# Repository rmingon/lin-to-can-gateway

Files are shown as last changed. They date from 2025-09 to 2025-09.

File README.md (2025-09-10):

# Secure LIN-to-CAN Gateway with AES Encryption

This project implements a **custom PCB gateway** that bridges **Local Interconnect Network (LIN)** and **Controller Area Network (CAN)** communication buses. It integrates **AES-based cryptographic software** to ensure secure message transfer across networks, making it suitable for both embedded research and industrial-grade applications.

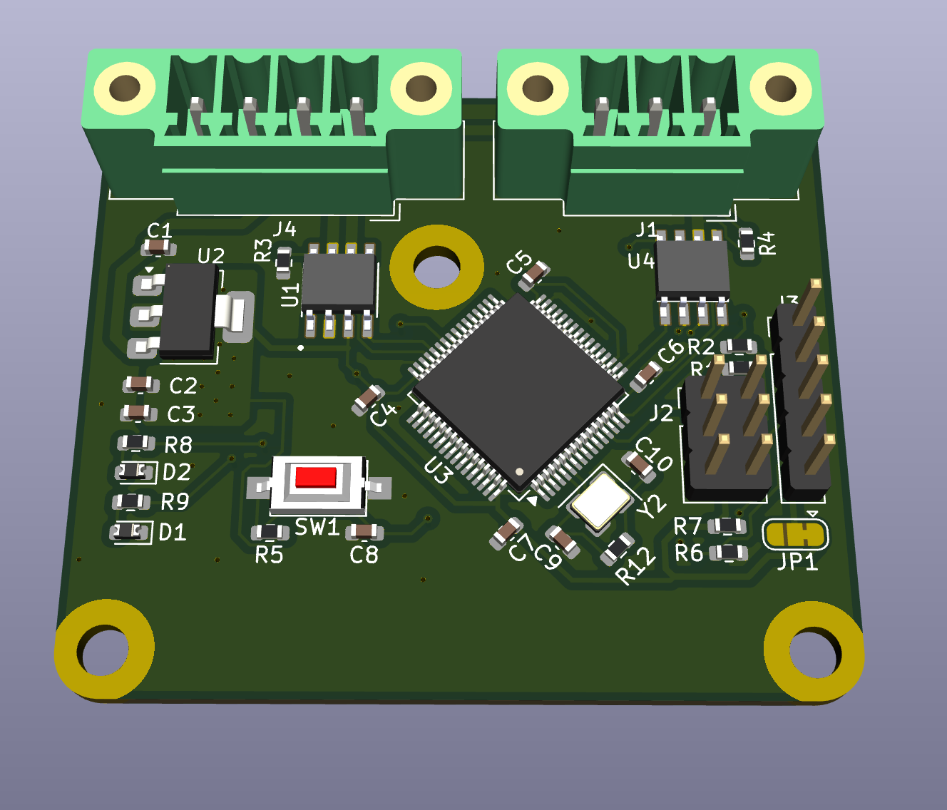
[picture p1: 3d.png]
3D


---

## Features

- **MCU Core:** STM32F107 microcontroller
- **CAN Transceiver:** MCP2551 for reliable CAN bus communication
- **LIN Transceiver:** TJA1020 for LIN bus interface
- **Crypto Layer:** AES software encryption for secure message payloads
- **Voltage Regulation:** On-board LM317 regulator provides stable 3.3V supply
- **Programming & Debugging:** SWD interface for firmware upload and debugging
- **User Interface:** Reset button, status LEDs, and configuration jumper
- **Compact PCB Design:** 2-layer PCB optimized for automotive and embedded systems

---

## Hardware Overview

### Major Components

- **U3 – STM32F107**: 32-bit ARM Cortex-M3 MCU
- **U1 – MCP2551**: High-speed CAN transceiver
- **U4 – TJA1020**: LIN transceiver for automotive communication
- **U2 – LM317**: Adjustable linear regulator, set to 3.3V output
- **Y2**: External crystal oscillator for precise MCU timing

### Connectors

- **J1 / J2**: LIN and CAN bus connections
- **J3**: SWD programming/debugging interface
- **JP1**: Boot configuration jumper

---

## Firmware

The firmware implements:

- LIN message reception, decryption, and forwarding to CAN
- CAN message reception, encryption, and forwarding to LIN
- AES-based payload encryption for secure communication
- Error handling and bus monitoring

---

## Applications

- **Automotive Systems:** Securely bridging LIN and CAN buses in vehicles
- **Industrial Automation:** Protecting data integrity across mixed communication buses
- **IoT Gateways:** Encrypted transport between legacy fieldbuses and modern networks
- **Research & Development:** Testing secure communication protocols in embedded systems

---

## Getting Started

1. **Assemble the PCB** with the provided KiCad files and BOM.
2. **Flash the firmware** via the SWD interface.
3. **Connect LIN and CAN networks** to the respective terminals.
4. **Test secure message transfer** with your chosen CAN/LIN monitoring tools.

---

## License

This project is licensed under the CERN Open Hardware Licence Version 2 - Strongly Reciprocal (CERN-OHL-S v2).

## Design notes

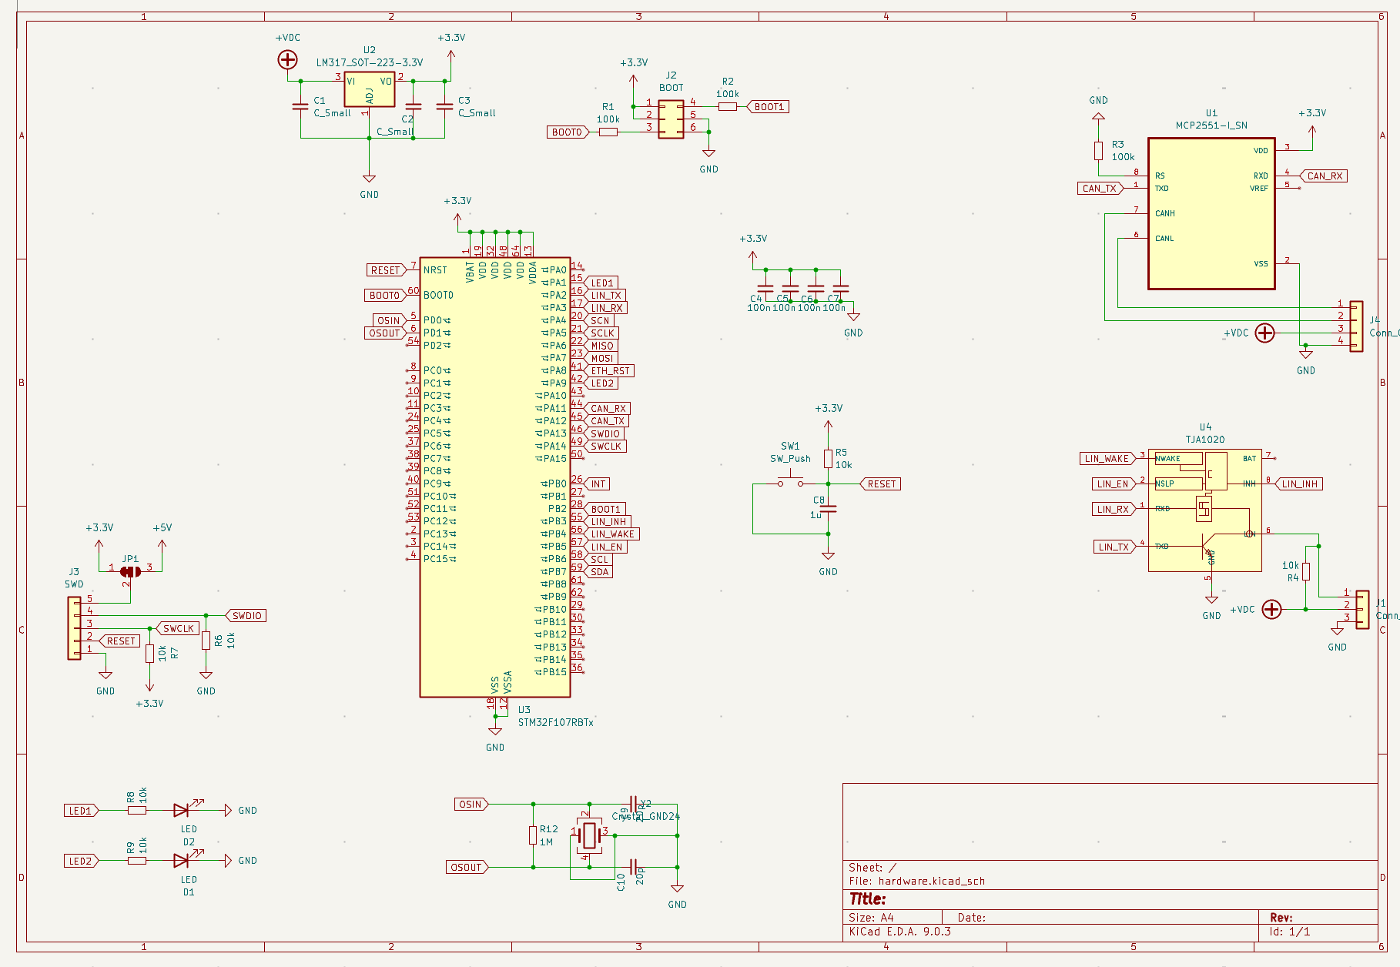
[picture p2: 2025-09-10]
schematic.png

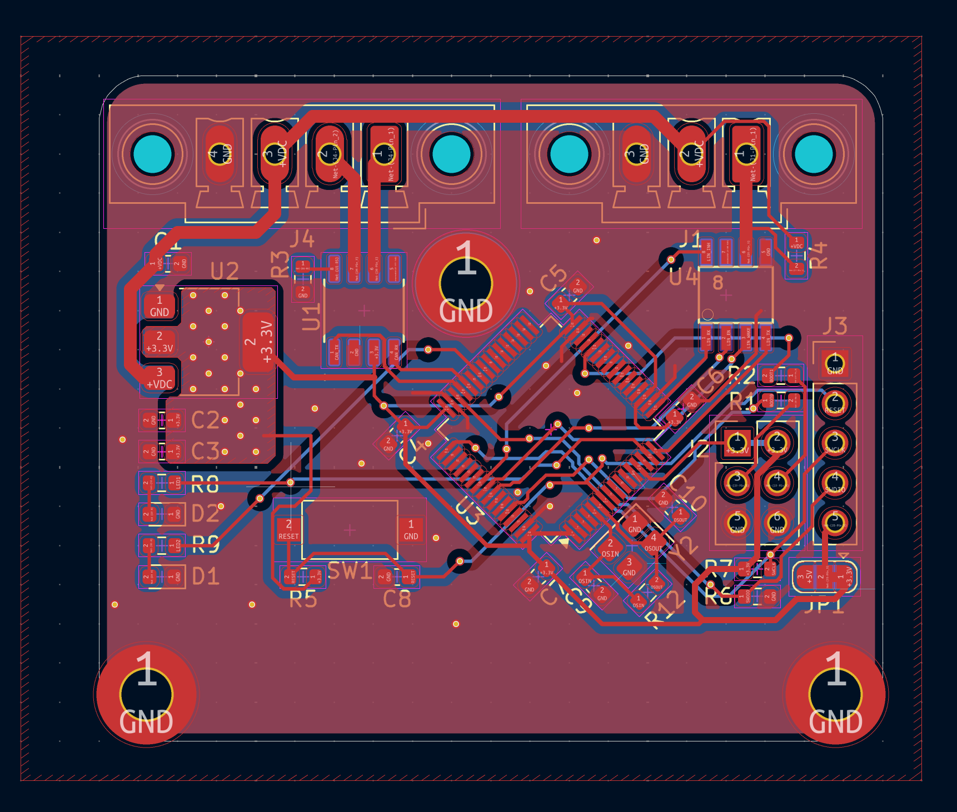
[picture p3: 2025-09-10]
pcb.png

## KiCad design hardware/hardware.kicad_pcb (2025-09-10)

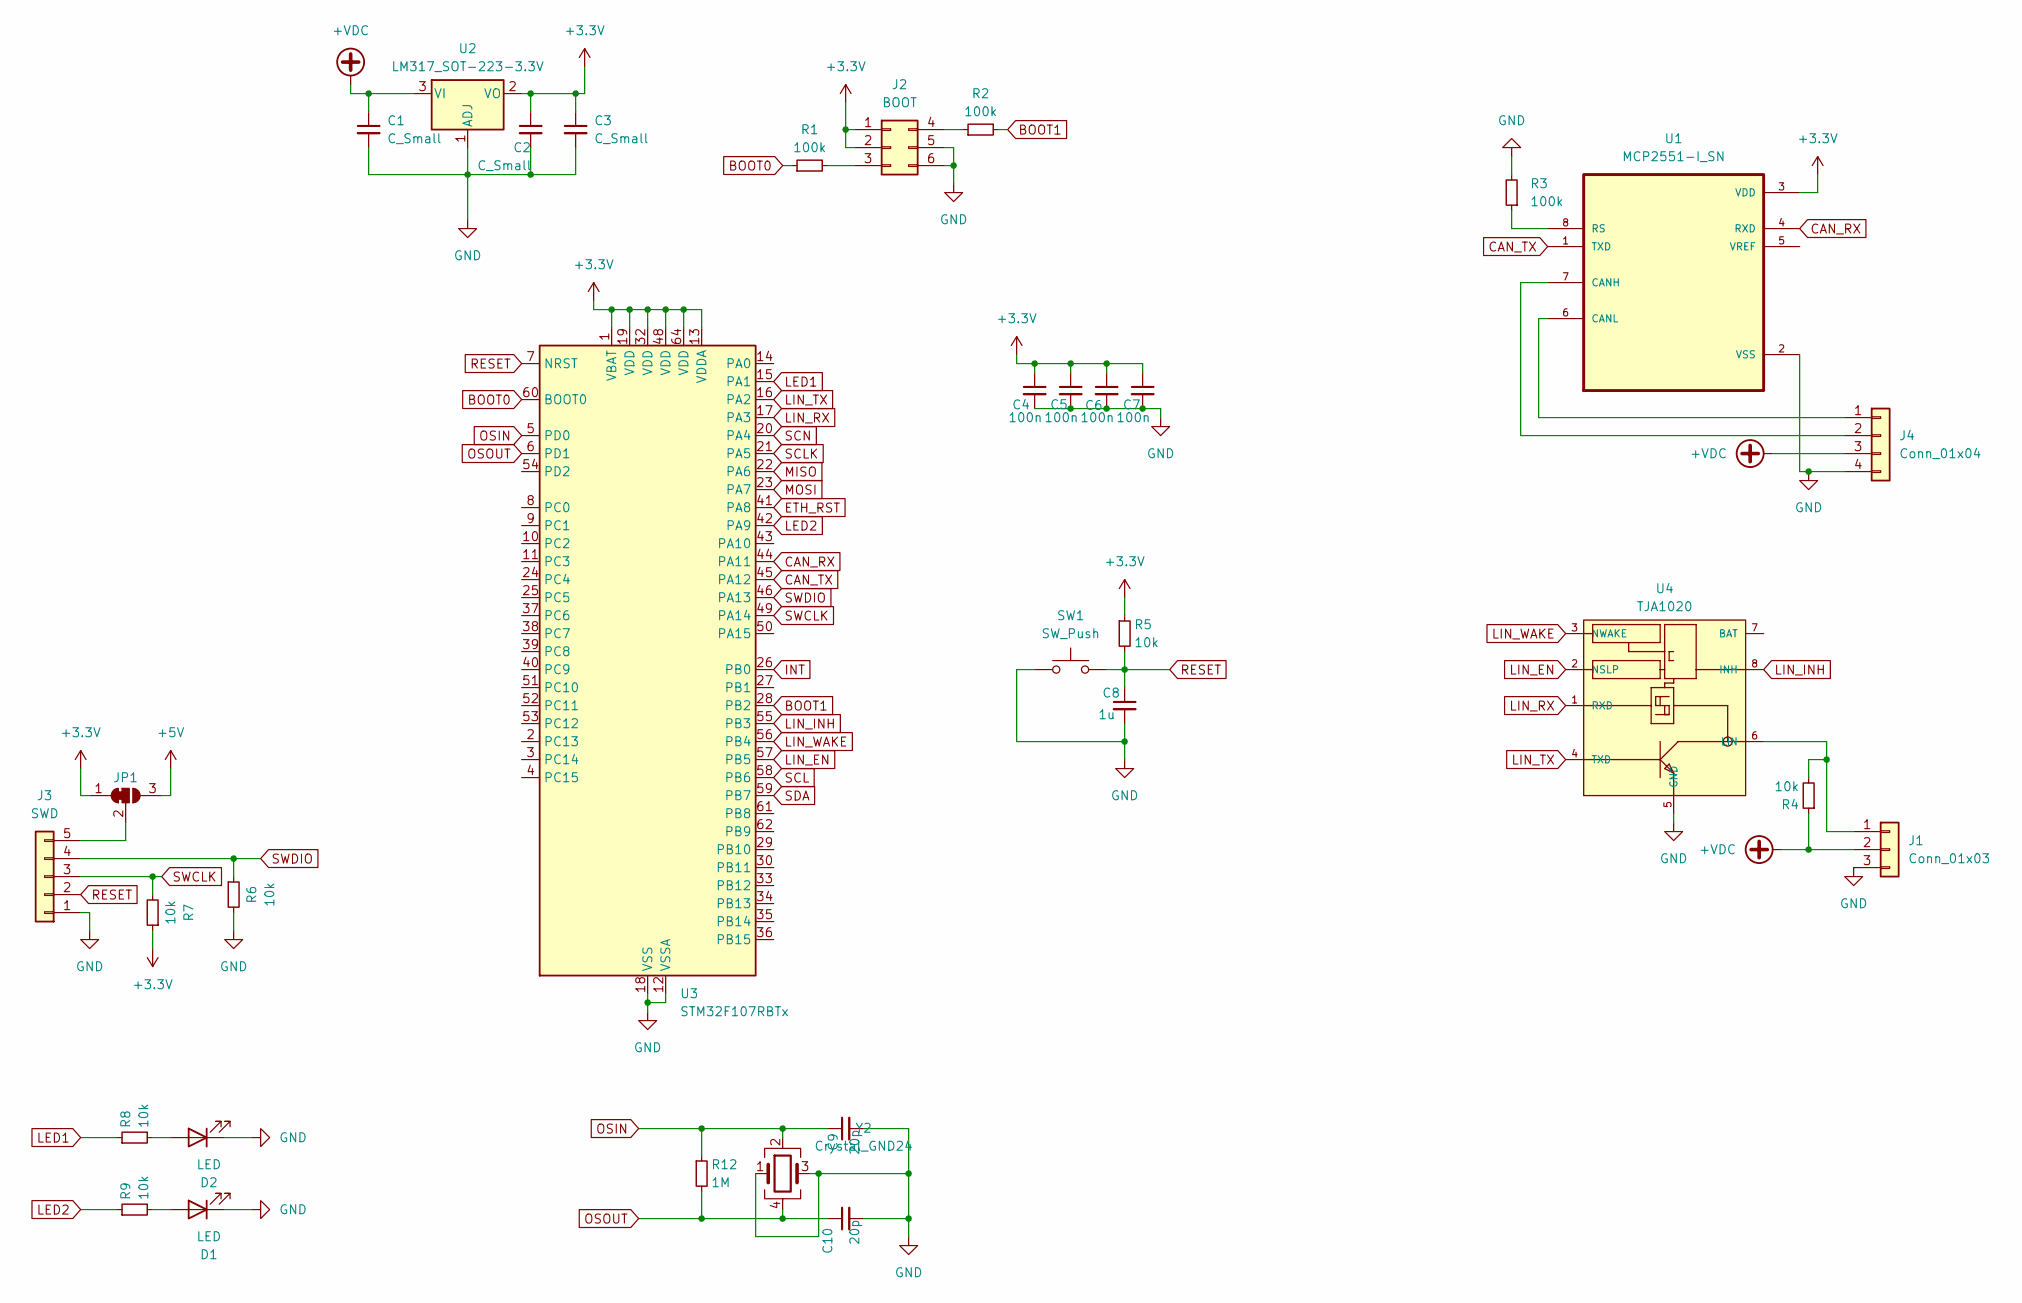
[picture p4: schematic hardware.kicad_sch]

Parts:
C1, C2, C3: C_Small; C_0603_1608Metric
C4, C5, C6, C7: 100n; C_0603_1608Metric
C8: 1u; C_0603_1608Metric
C9, C10: 20p; C_0603_1608Metric
D1, D2: LED; D_0603_1608Metric
J1: Conn_01x03; PhoenixContact_MCV_1,5_3-GF-3.5_1x03_P3.50mm_Vertical_Threa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
J2: BOOT; PinHeader_2x03_P2.54mm_Vertical_SMD
J3: SWD; PinHeader_1x05_P2.54mm_Vertical
J4: Conn_01x04; PhoenixContact_MCV_1,5_4-GF-3.5_1x04_P3.50mm_Vertical_Threa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
JP1: SolderJumper_3_Bridged12; SolderJumper-3_P1.3mm_Bridged12_RoundedPad1.0x1.5mm
R1, R2, R3: 100k; R_0603_1608Metric
R4, R5, R6, R7, R8, R9: 10k; R_0603_1608Metric
R12: 1M; R_0603_1608Metric
SW1: SW_Push; SW_SPST_CK_RS282G05A3
U1: MCP2551-I_SN; SOIC127P599X175-8N
U2: LM317_SOT-223-3.3V; SOT-223-3_TabPin2
U3: STM32F107RBTx; LQFP-64_10x10mm_P0.5mm
U4: TJA1020; SO8
Y2: Crystal_GND24; Crystal_SMD_3225-4Pin_3.2x2.5mm

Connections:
+3.3V: C2.1, C3.1, C4.1, C5.1, C6.1, C7.1, J2.1, J2.2, JP1.1 (A), R5.1, R7.1, U1.3 (VDD), U2.2 (VO), U3.1 (VBAT), U3.13 (VDDA), U3.19 (VDD), U3.32 (VDD), U3.48 (VDD), U3.64 (VDD)
+5V: JP1.3 (B)
+VDC: C1.1, J1.2, J4.3, R4.1, U2.3 (VI)
BOOT0: R1.1, U3.60 (BOOT0)
BOOT1: R2.2, U3.28 (PB2)
CAN_RX: U1.4 (RXD), U3.44 (PA11)
CAN_TX: U1.1 (TXD), U3.45 (PA12)
ETH_RST: U3.41 (PA8)
GND: C1.2, C2.2, C3.2, C4.2, C5.2, C6.2, C7.2, C8.2, C9.2, C10.2, D1.1 (K), D2.1 (K), J1.3, J2.5, J2.6, J3.1, J4.4, R3.2, R6.2, SW1.1, U1.2 (VSS), U2.1 (ADJ), U3.12 (VSSA), U3.18 (VSS), U3.31 (VSS), U3.47 (VSS), U3.63 (VSS), U4.5 (GND), Y2.1, Y2.3
INT: U3.26 (PB0)
LED1: R8.1, U3.15 (PA1)
LED2: R9.1, U3.42 (PA9)
LIN_EN: U3.57 (PB5), U4.2 (NSLP)
LIN_INH: U3.55 (PB3), U4.8 (INH)
LIN_RX: U3.17 (PA3), U4.1 (RXD)
LIN_TX: U3.16 (PA2), U4.4 (TXD)
LIN_WAKE: U3.56 (PB4), U4.3 (NWAKE)
MISO: U3.22 (PA6)
MOSI: U3.23 (PA7)
unnamed: D1.2 (A), R9.2
unnamed: D2.2 (A), R8.2
unnamed: J1.1, R4.2, U4.6 (LIN)
unnamed: J2.3, R1.2
unnamed: J2.4, R2.1
unnamed: J3.5, JP1.2 (C)
unnamed: J4.1, U1.6 (CANL)
unnamed: J4.2, U1.7 (CANH)
unnamed: R3.1, U1.8 (RS)
OSIN: C9.1, R12.1, U3.5 (PD0), Y2.2
OSOUT: C10.1, R12.2, U3.6 (PD1), Y2.4
RESET: C8.1, J3.2, R5.2, SW1.2, U3.7 (NRST)
SCL: U3.58 (PB6)
SCLK: U3.21 (PA5)
SCN: U3.20 (PA4)
SDA: U3.59 (PB7)
SWCLK: J3.3, R7.2, U3.49 (PA14)
SWDIO: J3.4, R6.1, U3.46 (PA13)

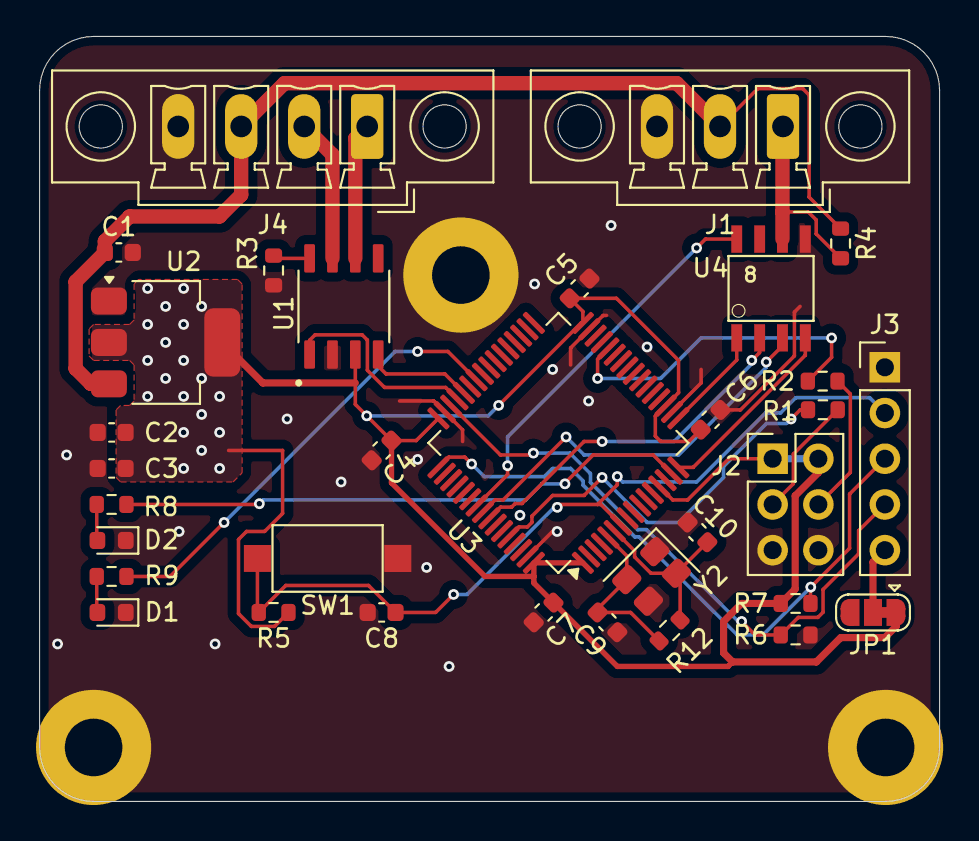
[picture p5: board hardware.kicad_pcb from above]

Board: 2 copper layers, 50.0 x 42.5 mm, 33 parts (0 on the bottom side), 28 nets.

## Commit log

2025-09-08 add minimal shematic components
    [hardware.kicad_pcb, hardware.kicad_sch]
2025-09-08 add lin control bus
    [hardware.kicad_pcb, hardware.kicad_sch]
2025-09-08 add lin + can connectors
    [hardware.kicad_pcb, hardware.kicad_sch]
2025-09-09 upgrade lin footprint
    [hardware.kicad_sch]
2025-09-09 fix boot 0 & boot 1 pin
    [hardware.kicad_pcb, hardware.kicad_sch]
2025-09-10 finish pcb wiring
    [hardware.kicad_pcb]
